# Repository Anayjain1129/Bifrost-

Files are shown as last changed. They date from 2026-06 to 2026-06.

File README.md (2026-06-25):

# Bifrost-







# Zine-Page
Group 274

### What is this project? 
This is a Split Keyboard made by a 15 year old teenager(me) from india. it uses XIAO nRF52840 as MCU and a battery connection too! which uses ZMK in firmware! 

### How to use/build it?
1. Break the PCB in 2 halves! 
2. Assemble the PCB with soldering iron by soldering the MCU, switches, and diodes
3. Plug in the MCU with PCB and then put the firmware file in it
4. Drag and drop the firmware file in the MCU  
5. Do the same things with other XIAO 
6. That's now you have your split keyboard working
7. Make sure to put it in an enclosure

### Why did i made this? 
I made this project to learn how does the XIAO-nRF52840-SMD MCUs work and how does the battery work with the PCBs and also to learn how to solder the SMD components, as they are so small in size and to master the soldering of componentes by hand.

### What was the Hardrest part?
All of the parts were hard and i think i learned so much from this project too! but using ZMK was the hardest part! but yea making this project did helped me to learn alot! 

# Features
- Seeed Studio XIAO 
- Custom Layout
- ZMK firmware
- Very cool case/enclosure to hold the PCB
- Uses nRF52840
- Uses magnets to keep things together

## Schematics 




## PCB



## 3d PCB




# Case
## Top





## Bottom





# 3d view of all parts together



assembly_2026-Jun-25_07-58-10AM-000_CustomizedView7371545002-Photoroom
assembly_2026-Jun-25_07-58-10AM-000_CustomizedView7371545002


# BOM
| Item | Description | Quantity | Unit Price (INR) | Total Price (INR) | Total Price (USD) | URL |
|---|---|---|---|---|---|-----|
| PCB | Printed Circuit Board | 5 | ₹834 | ₹4,170 | $44.18 | N/A |
| Seeed XIAO nRF52840 | Microcontroller | 2 | ₹1,152 | ₹2,304 | $24.41 | [Robu.in](https://robu.in/product/seeed-studio-xiao-ble-nrf52840/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) |
| Gateron Hotswap Sockets | Switch Sockets | 43 | ₹10 | ₹430 | $4.56 | [StacksKB](https://stackskb.com/store/gateron-hotswap-sockets/) |
| Cherry MX Switches | Switch | 50 | ₹18 | ₹900 | $9.54 | [Neomacro](https://neomacro.in/products/gateron-ef-cedar) |
| Blank DSA Keycaps 1u | Keycaps | 50 | ₹18.88 | ₹944 | $10.00 | [MecKeys](https://meckeys.com/shop/accessories/keyboard-accessories/keycaps/blank/blank-dsa-keycaps-1u/) |
| 3.7V LiPo Battery | Battery | 1 | ₹293 | ₹293 | $3.10 | [Amazon.in](https://www.amazon.in/Bhajanlal-Greenery-Rechargeable-Lithium-Batteries/dp/B0CYQ6H8FW?sr=8-3) |
| 1N4148WS SOD-123 | Diodes | 50 | ₹3 | ₹150 | $1.59 | [QuartzComponents](https://quartzcomponents.com/products/1n4148ws-t4-switching-diode-sod-123-smd-package?variant=45540031627498) |
| **TOTAL** | | | | **₹9,191** | **$97.38** | |

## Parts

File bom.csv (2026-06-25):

Item | Description | Quantity | Unit Price (INR) | Total Price (INR) | Total Price (USD) | URL
PCB | Printed Circuit Board | 5 | ₹834 | ₹4170 | $44.18 | N/A
Seeed XIAO nRF52840 | Microcontroller | 2 | ₹1152 | ₹2304 | $24.41 | https://robu.in/product/seeed-studio-xiao-ble-nrf52840/
Gateron Hotswap Sockets | Switch Sockets | 43 | ₹10 | ₹430 | $4.56 | https://stackskb.com/store/gateron-hotswap-sockets/
Cherry MX Switches | Switch | 50 | ₹18 | ₹900 | $9.54 | https://neomacro.in/products/gateron-ef-cedar
Blank DSA Keycaps 1u | Keycaps | 50 | ₹18.88 | ₹944 | $10.00 | https://meckeys.com/shop/accessories/keyboard-accessories/keycaps/blank/blank-dsa-keycaps-1u/
3.7V LiPo Battery | Battery | 1 | ₹293 | ₹293 | $3.10 | https://www.amazon.in/Bhajanlal-Greenery-Rechargeable-Lithium-Batteries/dp/B0CYQ6H8FW
1N4148WS SOD-123 | Diodes | 50 | ₹3 | ₹150 | $1.59 | https://quartzcomponents.com/products/1n4148ws-t4-switching-diode-sod-123-smd-package
TOTAL |  |  |  | ₹9191 | $97.38

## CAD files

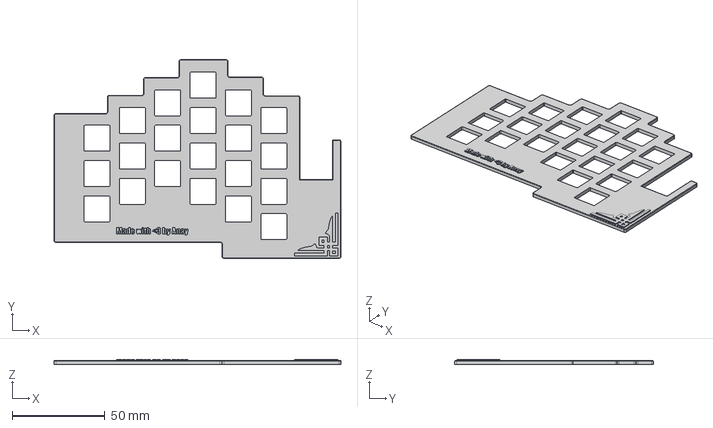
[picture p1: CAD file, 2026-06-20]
CAD/STEP/right_top.step
154.6 x 107.0 x 2.50 mm

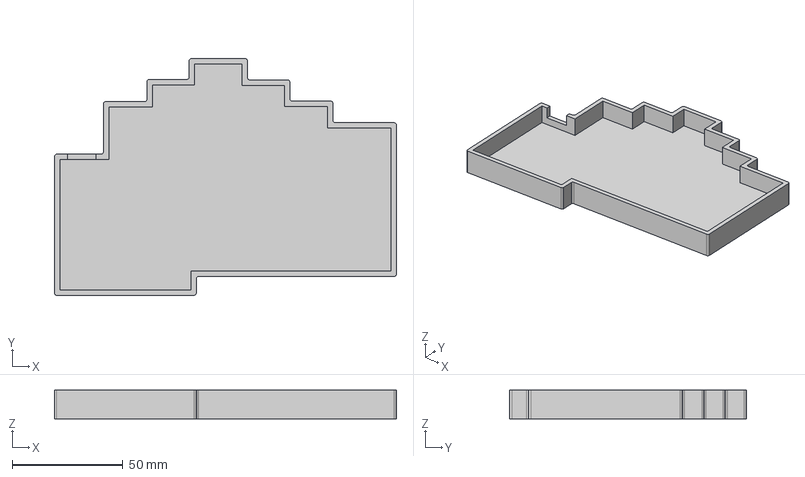
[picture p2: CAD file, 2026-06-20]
CAD/STEP/left_bottom.step
154.6 x 107.0 x 13.0 mm

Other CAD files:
CAD/STEP/left_top.step
CAD/STEP/right_bottom.step
CAD/STL/left_bottom.stl
CAD/STL/left_top.stl
CAD/STL/right_top.stl
CAD/f3d/left_bottom.f3d
CAD/f3d/left_top.f3d
CAD/f3d/right_bottom.f3d
CAD/f3d/right_top.f3d

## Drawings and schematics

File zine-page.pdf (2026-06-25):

# BI-FROST

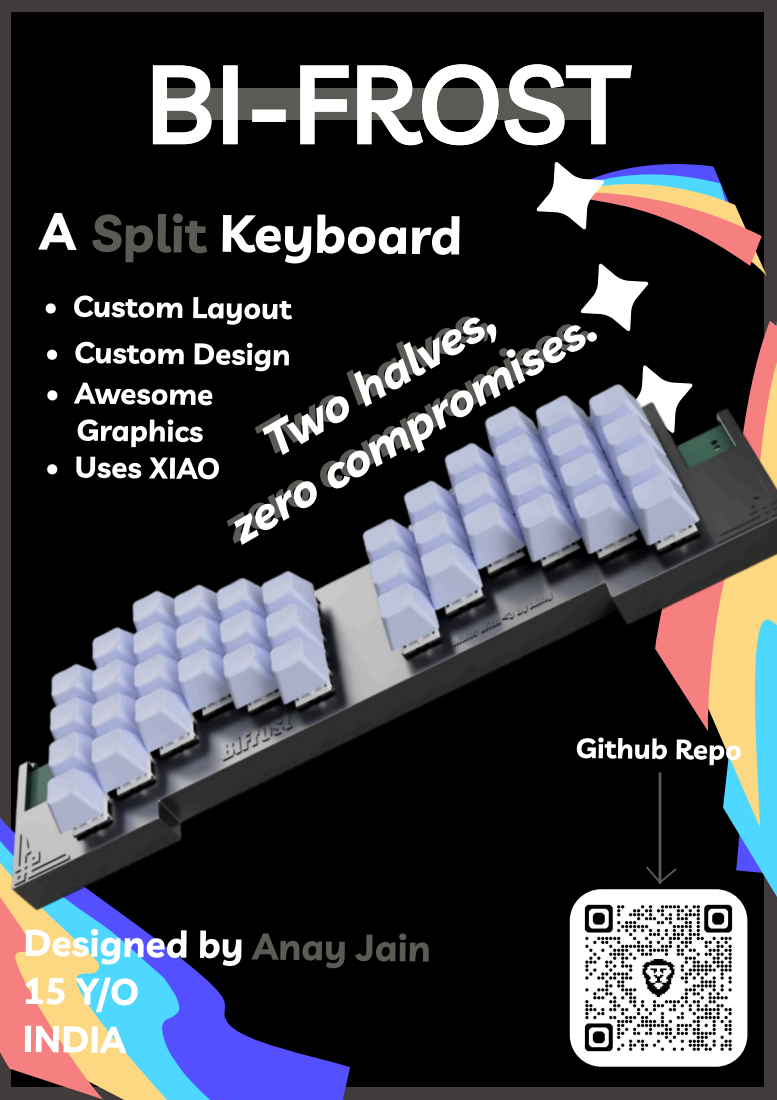
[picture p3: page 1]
Custom Layout; Custom Design; Awesome; Graphics; Uses XIAO; A Keyboard Split; Two halves, zero compromises.; Github Repo; Designed by 15 Y/O; Anay Jain; INDIA

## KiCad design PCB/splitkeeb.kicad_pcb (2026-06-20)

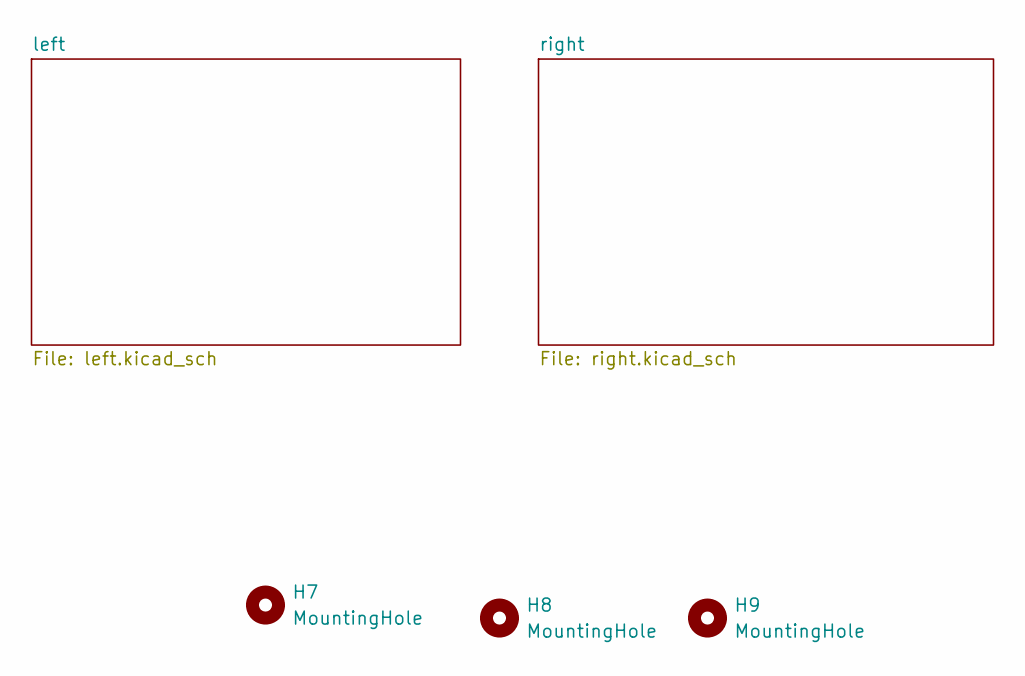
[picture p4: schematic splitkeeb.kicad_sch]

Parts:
H7, H8, H9: MountingHole; mouse-bite-2mm-slot

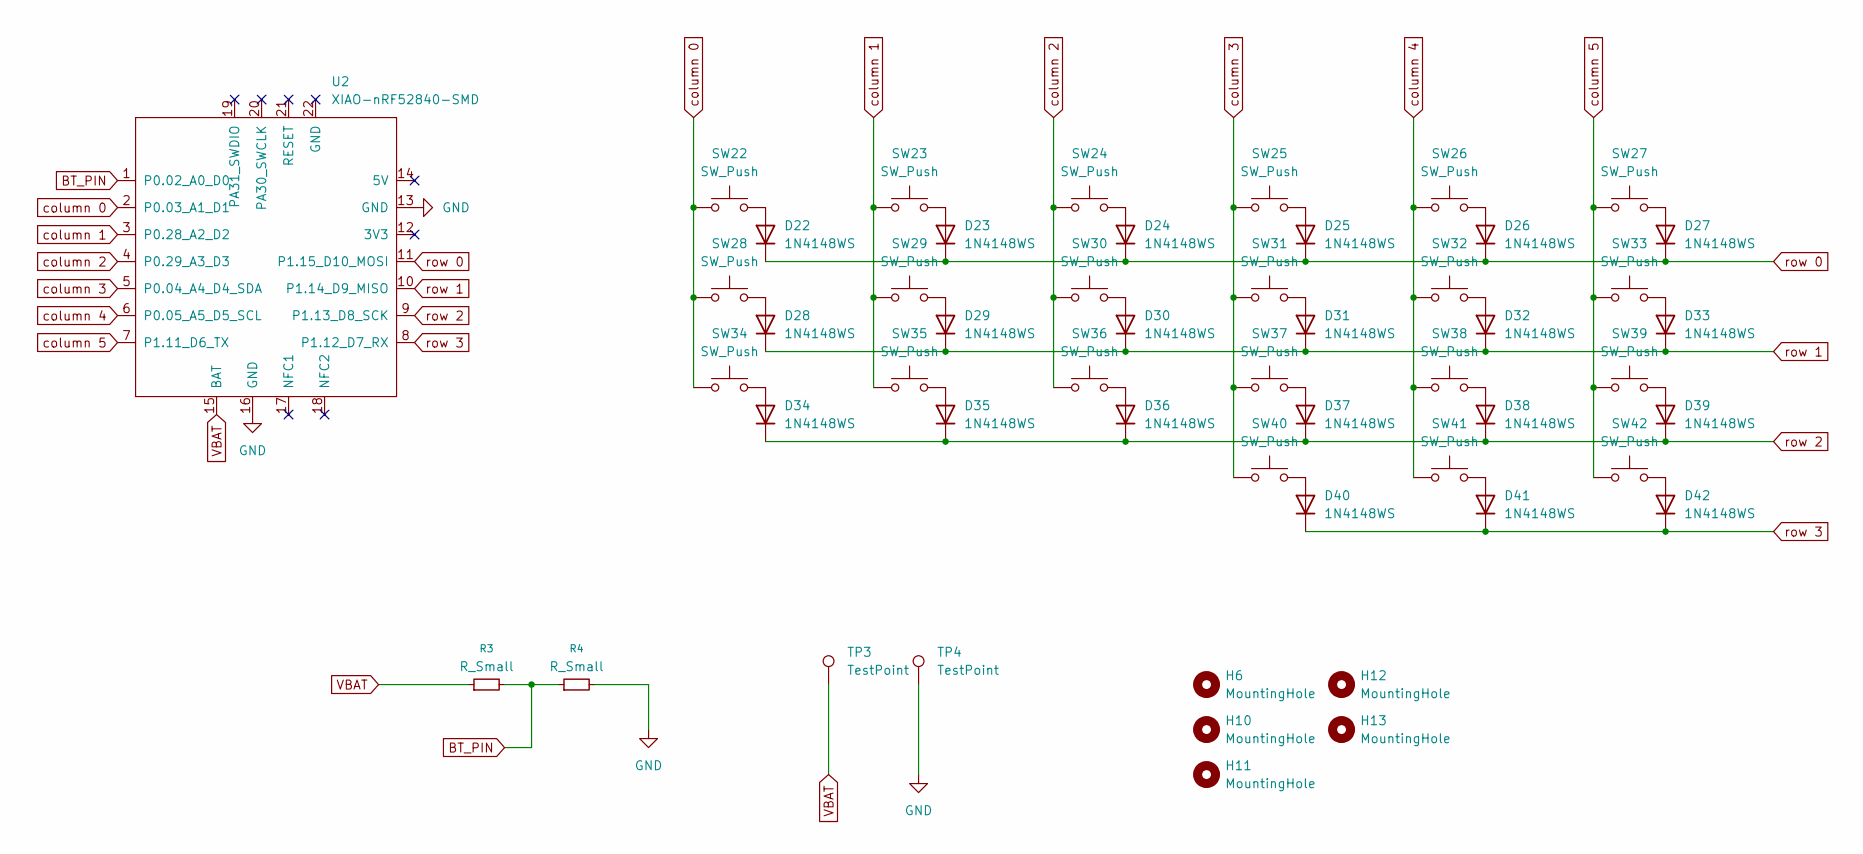
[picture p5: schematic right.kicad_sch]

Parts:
D22, D23, D24, D25, D26, D27, D28, D29, D30, D31, D32, D33, D34, D35, D36, D37, D38, D39, D40, D41, D42: 1N4148WS; D_SOD-323
H6, H10, H11, H12, H13: MountingHole; MountingHole_2.2mm_M2
R3, R4: R_Small; R_0805_2012Metric
SW22, SW23, SW24, SW25, SW26, SW27, SW28, SW29, SW30, SW31, SW32, SW33, SW34, SW35, SW36, SW37, SW38, SW39, SW40, SW41, SW42: SW_Push; Hotswap_MX_1.00u
TP3, TP4: TestPoint; TestPoint_Pad_D2.0mm
U2: XIAO-nRF52840-SMD; modified-XIAO-nRF52840-SMD

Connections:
BT_PIN: R3.2, R4.1, U2.1 (P0.02_A0_D0); also elsewhere on the board
GND: R4.2, TP4.1 (1_1), U2.13 (GND), U2.16 (GND); also elsewhere on the board
unnamed: D22.2 (A), SW22.2
unnamed: D23.2 (A), SW23.2
unnamed: D24.2 (A), SW24.2
unnamed: D25.2 (A), SW25.2
unnamed: D26.2 (A), SW26.2
unnamed: D27.2 (A), SW27.2
unnamed: D28.2 (A), SW28.2
unnamed: D29.2 (A), SW29.2
unnamed: D30.2 (A), SW30.2
unnamed: D31.2 (A), SW31.2
unnamed: D32.2 (A), SW32.2
unnamed: D33.2 (A), SW33.2
unnamed: D34.2 (A), SW34.2
unnamed: D35.2 (A), SW35.2
unnamed: D36.2 (A), SW36.2
unnamed: D37.2 (A), SW37.2
unnamed: D38.2 (A), SW38.2
unnamed: D39.2 (A), SW39.2
unnamed: D40.2 (A), SW40.2
unnamed: D41.2 (A), SW41.2
unnamed: D42.2 (A), SW42.2
VBAT: R3.1, TP3.1 (1_1), U2.15 (BAT); also elsewhere on the board
column 0: SW22.1, SW28.1, SW34.1, U2.2 (P0.03_A1_D1); also elsewhere on the board
column 1: SW23.1, SW29.1, SW35.1, U2.3 (P0.28_A2_D2); also elsewhere on the board
column 2: SW24.1, SW30.1, SW36.1, U2.4 (P0.29_A3_D3); also elsewhere on the board
column 3: SW25.1, SW31.1, SW37.1, SW40.1, U2.5 (P0.04_A4_D4_SDA); also elsewhere on the board
column 4: SW26.1, SW32.1, SW38.1, SW41.1, U2.6 (P0.05_A5_D5_SCL); also elsewhere on the board
column 5: SW27.1, SW33.1, SW39.1, SW42.1, U2.7 (P1.11_D6_TX); also elsewhere on the board
row 0: D22.1 (K), D23.1 (K), D24.1 (K), D25.1 (K), D26.1 (K), D27.1 (K), U2.11 (P1.15_D10_MOSI); also elsewhere on the board
row 1: D28.1 (K), D29.1 (K), D30.1 (K), D31.1 (K), D32.1 (K), D33.1 (K), U2.10 (P1.14_D9_MISO); also elsewhere on the board
row 2: D34.1 (K), D35.1 (K), D36.1 (K), D37.1 (K), D38.1 (K), D39.1 (K), U2.9 (P1.13_D8_SCK); also elsewhere on the board
row 3: D40.1 (K), D41.1 (K), D42.1 (K), U2.8 (P1.12_D7_RX); also elsewhere on the board

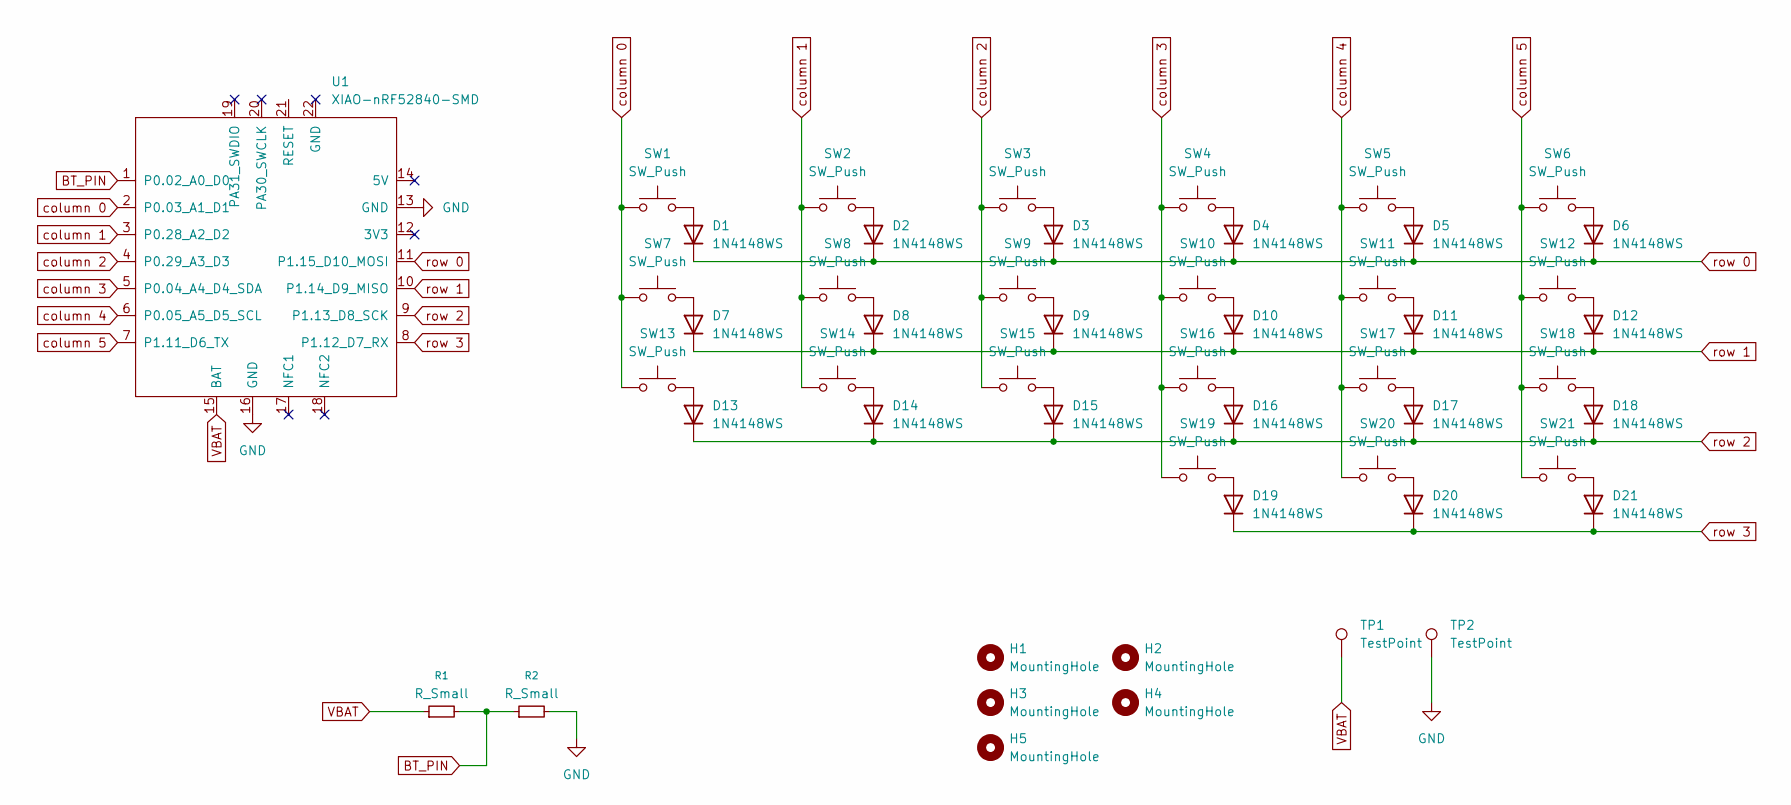
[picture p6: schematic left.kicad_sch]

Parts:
D1, D2, D3, D4, D5, D6, D7, D8, D9, D10, D11, D12, D13, D14, D15, D16, D17, D18, D19, D20, D21: 1N4148WS; D_SOD-323
H1, H2, H3, H4, H5: MountingHole; MountingHole_2.2mm_M2
R1, R2: R_Small; R_0805_2012Metric
SW1, SW2, SW3, SW4, SW5, SW6, SW7, SW8, SW9, SW10, SW11, SW12, SW13, SW14, SW15, SW16, SW17, SW18, SW19, SW20, SW21: SW_Push; Hotswap_MX_1.00u
TP1, TP2: TestPoint; TestPoint_Pad_D2.0mm
U1: XIAO-nRF52840-SMD; modified-XIAO-nRF52840-SMD

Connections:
BT_PIN: R1.2, R2.1, U1.1 (P0.02_A0_D0); also elsewhere on the board
GND: R2.2, TP2.1 (1_1), U1.13 (GND), U1.16 (GND); also elsewhere on the board
unnamed: D1.2 (A), SW1.2
unnamed: D2.2 (A), SW2.2
unnamed: D3.2 (A), SW3.2
unnamed: D4.2 (A), SW4.2
unnamed: D5.2 (A), SW5.2
unnamed: D6.2 (A), SW6.2
unnamed: D7.2 (A), SW7.2
unnamed: D8.2 (A), SW8.2
unnamed: D9.2 (A), SW9.2
unnamed: D10.2 (A), SW10.2
unnamed: D11.2 (A), SW11.2
unnamed: D12.2 (A), SW12.2
unnamed: D13.2 (A), SW13.2
unnamed: D14.2 (A), SW14.2
unnamed: D15.2 (A), SW15.2
unnamed: D16.2 (A), SW16.2
unnamed: D17.2 (A), SW17.2
unnamed: D18.2 (A), SW18.2
unnamed: D19.2 (A), SW19.2
unnamed: D20.2 (A), SW20.2
unnamed: D21.2 (A), SW21.2
VBAT: R1.1, TP1.1 (1_1), U1.15 (BAT); also elsewhere on the board
column 0: SW1.1, SW7.1, SW13.1, U1.2 (P0.03_A1_D1); also elsewhere on the board
column 1: SW2.1, SW8.1, SW14.1, U1.3 (P0.28_A2_D2); also elsewhere on the board
column 2: SW3.1, SW9.1, SW15.1, U1.4 (P0.29_A3_D3); also elsewhere on the board
column 3: SW4.1, SW10.1, SW16.1, SW19.1, U1.5 (P0.04_A4_D4_SDA); also elsewhere on the board
column 4: SW5.1, SW11.1, SW17.1, SW20.1, U1.6 (P0.05_A5_D5_SCL); also elsewhere on the board
column 5: SW6.1, SW12.1, SW18.1, SW21.1, U1.7 (P1.11_D6_TX); also elsewhere on the board
row 0: D1.1 (K), D2.1 (K), D3.1 (K), D4.1 (K), D5.1 (K), D6.1 (K), U1.11 (P1.15_D10_MOSI); also elsewhere on the board
row 1: D7.1 (K), D8.1 (K), D9.1 (K), D10.1 (K), D11.1 (K), D12.1 (K), U1.10 (P1.14_D9_MISO); also elsewhere on the board
row 2: D13.1 (K), D14.1 (K), D15.1 (K), D16.1 (K), D17.1 (K), D18.1 (K), U1.9 (P1.13_D8_SCK); also elsewhere on the board
row 3: D19.1 (K), D20.1 (K), D21.1 (K), U1.8 (P1.12_D7_RX); also elsewhere on the board

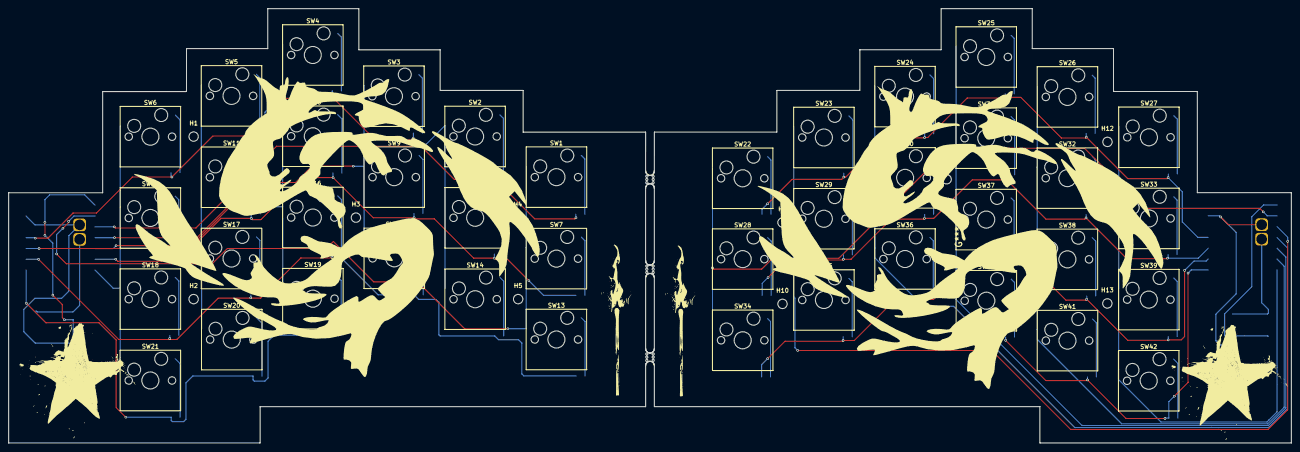
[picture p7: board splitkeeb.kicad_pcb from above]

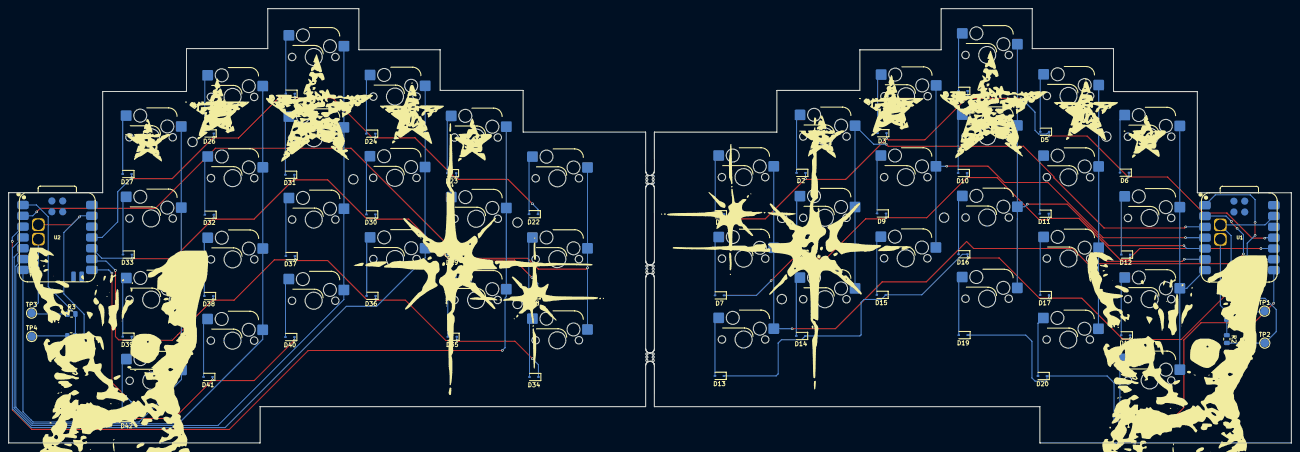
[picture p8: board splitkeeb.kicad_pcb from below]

Board: 2 copper layers, 301.1 x 102.0 mm, 107 parts (52 on the bottom side), 55 nets.

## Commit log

2026-06-20 case files
    [left_bottom.f3d, left_bottom.step, left_bottom.stl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]
2026-06-20 added the gerber files
    [splitkeeb-B_Cu.gbr, splitkeeb-B_Mask.gbr, splitkeeb-B_Paste.gbr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]
2026-06-20 Add Bill of Materials section to README
    Added a Bill of Materials (BOM) section with item details and pricing.
2026-06-20 Remove Bill of Materials section from README
    Removed the Bill of Materials section from the README.
2026-06-25 Add images to 3d PCB section in README
    Added new images to the 3d PCB section of the README.
